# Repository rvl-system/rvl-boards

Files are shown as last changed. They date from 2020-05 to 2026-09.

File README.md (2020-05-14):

# RVL Controller Board

_**Note:**_ This board is still in development, and documentation is currently sparse.

The RVL controller board is a custom board that runs the [RVL Firmware](https://github.com/rvl-system/rvl-firmware), and is intended for use as both a development board and an LED controller. This board features:

- ESP32 dual core processor
- Compatible with 3 or 4 pin 5V LED strips supported by [FastLED](http://fastled.io/)
  - Solder jumper for switching between 3 and 4 pin headers (optional)
- Can be powered from USB, or can be "backfed" power from the LED strip connected to it
- 3.3V to 5V level translation on LED control pins
- An LCD and tiny 5-way joystick for controlling the device directly
- A 16-pin header, with GPIO, UART, JTAG, I2C, and ADC pins exposed
- Can be programmed using JTAG + [OpenOCD](https://docs.espressif.com/projects/esp-idf/en/latest/api-guides/jtag-debugging/#jtag-debugging-setup-openocd) or UART + [esptool.py](https://github.com/espressif/esptool)
  - JTAG is the recommended way to interact with this device. The experience is a lot smoother, and you can also debug the device with breakpoints/variable inspection.
  - [RVL Firmware](https://github.com/rvl-system/rvl-firmware) includes a script that is preconfigured to use JTAG+OpenOCD with this device and the [FTDI C232HM-DDHSL-0](https://www.ftdichip.com/Products/Cables/USBMPSSE.htm) MSSPE cable 
  
## GPIO Header Pins

The GPIO header has the following layout:

<table>
  <tr>
    <td>TMS</td><td>TCK</td><td>GND</td><td>26</td><td>25</td><td>18</td><td>23</td><td>VCC</td>
  </tr>
  <tr>
    <td>TDI</td><td>TDO</td><td>RXD</td><td>TXD</td><td>27</td><td>5</td><td>19</td><td>GND</td>
  </tr>
</table>

Each pin has the following functionality*:

|Pin|Functions|
|--|--|
| TMS | GPIO14, ADC2_CH6, TOUCH6, RTC_GPIO16, MTMS, HSPICLK, HS2_CLK, SD_CLK, EMAC_TXD2 |
| TDI | GPIO12, ADC2_CH5, TOUCH5, RTC_GPIO15, MTDI, HSPIQ, HS2_DATA2, SD_DATA2, EMAC_TXD3 |
| TCK | GPIO13, ADC2_CH4, TOUCH4, RTC_GPIO14, MTCK, HSPID, HS2_DATA3, SD_DATA3, EMAC_RX_ER |
| TDO | GPIO15, ADC2_CH3, TOUCH3, MTDO, HSPICS0, RTC_GPIO13, HS2_CMD, SD_CMD, EMAC_RXD3 |
| GND | Ground (shown as EN in the photo, but has been changed in the most recent revision) |
| RXD | GPIO3, U0RXD, CLK_OUT2 |
| 26  | GPIO26, DAC_2, ADC2_CH9, RTC_GPIO7, EMAC_RXD1 |
| TXD | GPIO1, U0TXD, CLK_OUT3, EMAC_RXD2 |
| 25  | GPIO25, DAC_1, ADC2_CH8, RTC_GPIO6, EMAC_RXD0 |
| 27  | GPIO27, ADC2_CH7, TOUCH7, RTC_GPIO17, EMAC_RX_DV |
| 23  | GPIO23, GPIO23, HS1_STROBE, VSPID/VSPIMOSI |
| 18  | GPIO18, GPIO18, HS1_DATA7, VSPICLK |
| 19  | GPIO19, GPIO19, U0CTS, VSPIQ/VSPMISO, EMAC_TXD0 |
| 5  | GPIO5, GPIO5, HS1_DATA6, VSPICS0, EMAC_RX_CLK |
| VCC | 3.3 volt power (limited to 500mA total including CPU) |
| GND | Ground  |

*This data comes from the [ESP32 WROOM datasheet](https://www.espressif.com/sites/default/files/documentation/esp32-wroom-32_datasheet_en.pdf).

## Photos

Here is the front of the board:

Board front

Here is the back of the board:

Board back

Here is the board running with a WS2812b LED strip attached

Board running with LEDs attached

And here is a video of an art piece I designed the lighting for using an older version of this board at Burning Man 2019:

<a href="https://www.youtube.com/watch?v=HZNM6n1g5n8" target="_blank">
  Video of the BRPL Deep Playa Branch at Burning Man 2019
</a>

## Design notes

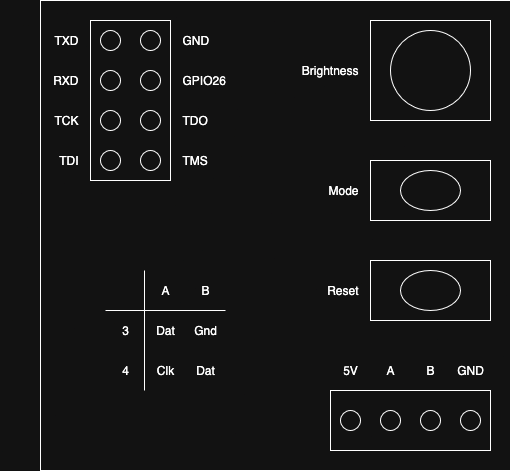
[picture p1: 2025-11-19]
receiver/pinout.png

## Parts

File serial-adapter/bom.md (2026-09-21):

# Bill of Materials

| Part Number | Description | Quantity | Unit Cost&ast; | Total Cost&ast; |
|---|---|---|---|---|
| [RMCF0805ZT0R00](https://www.digikey.com/en/products/detail/stackpole-electronics-inc/RMCF0805ZT0R00/1756901) | RES 0 OHM JUMPER 1/8W 0805 | 2 | $0.10 | $0.20 |
| [ERJ-6GEYJ222V](https://www.digikey.com/en/products/detail/panasonic-industry/ERJ-6GEYJ222V/83030) | RES SMD 2.2K OHM 5% 1/8W 0805 | 2 | $0.10 | $0.20 |
| [150080RS75000](https://www.digikey.com/product-detail/en/w-rth-elektronik/150080RS75000/732-4984-1-ND/4489916) | LED RED CLEAR 0805 SMD | 2 | $0.19 | $0.38 |
| [0532610571](https://www.digikey.com/en/products/detail/molex/0532610571/699097) | CONN HEADER SMD R/A 5POS 1.25MM | 1 | $0.85 | $0.85 |
| | CONN HDR 6POS 0.1" PITCH R/A&ast;&ast; | 1 | &mdash; | &mdash; |
| [KMR641NG ULC LFS](https://www.digikey.com/product-detail/en/c-k/KMR641NG-ULC-LFS/CKN10686CT-ND/6035358) | SWITCH TACTILE SPST-NO 50MA 32V | 2 | $0.96 | $1.92 |
| [RVL Serial Adapter board](https://oshpark.com/projects/qkIF3fA0) | Custom OSH Park board | 1 | $1.03 | $1.03 |
| | | | | **$4.58** |

&ast; All prices in USD. Prices current as of September 21st, 2026.

&ast;&ast; A generic 6 position 0.1" (2.54mm) pitch right angle pin header. These are
commonly bought as long breakaway strips and cut to size, so no specific part
number or price is listed, and it is excluded from the total.

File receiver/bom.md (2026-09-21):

# Bill of Materials

| Part Number | Description | Quantity | Unit Cost&ast; | Total Cost&ast; |
|---|---|---|---|---|
| [CC0805KKX5R5BB105](https://www.digikey.com/en/products/detail/yageo/CC0805KKX5R5BB105/5884149) | CAP CER 1UF 6.3V X5R 0805 | 1 | $0.26 | $0.26 |
| [CL21A475KQFNNNG](https://www.digikey.com/product-detail/en/samsung-electro-mechanics/CL21A475KQFNNNG/1276-6465-1-ND/5958093) | CAP CER 4.7UF 6.3V X5R 0805 | 1 | $0.13 | $0.13 |
| [CC0805MRX5R5BB106](https://www.digikey.com/en/products/detail/yageo/CC0805MRX5R5BB106/7164457) | CAP CER 10UF 6.3V X5R 0805 | 1 | $0.38 | $0.38 |
| [74479275222](https://www.digikey.com/product-detail/en/w-rth-elektronik/74479275222/732-9708-1-ND/5870862) | FIXED IND 2.2UH 2A 190 MOHM | 1 | $1.27 | $1.27 |
| [ERJ-6GEYJ680V](https://www.digikey.com/en/products/detail/panasonic-electronic-components/ERJ-6GEYJ680V/83006) | RES SMD 68 OHM 5% 1/8W 0805 | 1 | $0.10 | $0.10 |
| [ERJ-6GEYJ102V](https://www.digikey.com/product-detail/en/panasonic-electronic-components/ERJ-6GEYJ102V/P1-0KACT-ND/42833) | RES SMD 1K OHM 5% 1/8W 0805 | 1 | $0.10 | $0.10 |
| [TC33X-2-202E](https://www.digikey.com/en/products/detail/bourns-inc/TC33X-2-202E/612860) | TRIMMER 2K OHM 0.15W J LEAD TOP | 1 | $0.28 | $0.28 |
| [ERJ-6GEYJ103V](https://www.digikey.com/product-detail/en/panasonic-electronic-components/ERJ-6GEYJ103V/P10KACT-ND/43118) | RES SMD 10K OHM 5% 1/8W 0805 | 5 | $0.10 | $0.50 |
| [150080RS75000](https://www.digikey.com/product-detail/en/w-rth-elektronik/150080RS75000/732-4984-1-ND/4489916) | LED RED CLEAR 0805 SMD | 1 | $0.19 | $0.19 |
| [10118194-0001LF](https://www.digikey.com/product-detail/en/amphenol-icc-fci/10118194-0001LF/609-4618-1-ND/2785382) | CONN RCPT USB2.0 MICRO B SMD R/A | 1 | $0.47 | $0.47 |
| [OSTTE040104](https://www.digikey.com/en/products/detail/on-shore-technology-inc/OSTTE040104/2351818) | TERM BLK 4POS SIDE ENT 3.5MM PCB | 1 | $1.00 | $1.00 |
| [PPTC042LFBN-RC](https://www.digikey.com/en/products/detail/sullins-connector-solutions/PPTC042LFBN-RC/810211) | CONN HDR 8POS 0.1 TIN PCB | 1 | $0.65 | $0.65 |
| [219-3LPST](https://www.digikey.com/en/products/detail/cts-electrocomponents/219-3LPST/223166) | SWITCH DIP SLIDE SPST 100MA 20V | 1 | $0.54 | $0.54 |
| [KMR641NG ULC LFS](https://www.digikey.com/product-detail/en/c-k/KMR641NG-ULC-LFS/CKN10686CT-ND/6035358) | SWITCH TACTILE SPST-NO 50MA 32V | 2 | $0.96 | $1.92 |
| [ESP32-WROOM-32E](https://www.digikey.com/en/products/detail/espressif-systems/ESP32-WROOM-32E-N4/11613125) | ESP-32 WiFi Microcontroller | 1 | $4.99 | $4.99 |
| [LM3671MF-3.3/NOPB](https://www.digikey.com/product-detail/en/texas-instruments/LM3671MF-3.3-NOPB/LM3671MF-3.3-NOPBCT-ND/1590190) | IC REG BUCK 3.3V 600MA SOT23-5 | 1 | $1.99 | $1.99 |
| [SN74LVC1T45DBVR](https://www.digikey.com/product-detail/en/texas-instruments/SN74LVC1T45DBVR/296-16843-1-ND/639459) | IC TRNSLTR BIDIRECTIONAL SOT23-6 | 2 | $0.62 | $1.24 |
| [RVL Receiver v1.7 board](https://oshpark.com/shared_projects/RHi5VRXz) | Custom OSH Park board | 1 | $3.76 | $3.76 |
| | | | | **$19.77** |

&ast; All prices in USD. Prices current as of September 21st, 2026.

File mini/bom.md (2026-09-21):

# Bill of Materials

| Part Number | Description | Quantity | Unit Cost&ast; | Total Cost&ast; |
|---|---|---|---|---|
| [CL21B104KCCWPNC](https://www.digikey.com/en/products/detail/samsung-electro-mechanics/CL21B104KCCWPNC/5961334) | CAP CER 0.1UF 100V X7R 0805 | 2 | $0.29 | $0.58 |
| [CC0805KKX5R5BB105](https://www.digikey.com/en/products/detail/yageo/CC0805KKX5R5BB105/5884149) | CAP CER 1UF 6.3V X5R 0805 | 1 | $0.26 | $0.26 |
| [CL21A475KQFNNNG](https://www.digikey.com/product-detail/en/samsung-electro-mechanics/CL21A475KQFNNNG/1276-6465-1-ND/5958093) | CAP CER 4.7UF 6.3V X5R 0805 | 1 | $0.13 | $0.13 |
| [CC0805MRX5R5BB106](https://www.digikey.com/en/products/detail/yageo/CC0805MRX5R5BB106/7164457) | CAP CER 10UF 6.3V X5R 0805 | 1 | $0.38 | $0.38 |
| [74479275222](https://www.digikey.com/product-detail/en/w-rth-elektronik/74479275222/732-9708-1-ND/5870862) | FIXED IND 2.2UH 2A 190 MOHM | 1 | $1.27 | $1.27 |
| [ERJ-6GEYJ680V](https://www.digikey.com/en/products/detail/panasonic-industry/ERJ-6GEYJ680V/83006) | RES SMD 68 OHM 5% 1/8W 0805 | 1 | $0.10 | $0.10 |
| [ERJ-6GEYJ221V](https://www.digikey.com/en/products/detail/panasonic-electronic-components/ERJ-6GEYJ221V/89706) | RES SMD 220 OHM 5% 1/8W 0805 | 1 | $0.10 | $0.10 |
| [ERJ-6GEYJ331V](https://www.digikey.com/en/products/detail/panasonic-industry/ERJ-6GEYJ331V/89726) | RES SMD 330 OHM 5% 1/8W 0805 | 2 | $0.10 | $0.20 |
| [ERJ-6GEYJ103V](https://www.digikey.com/product-detail/en/panasonic-electronic-components/ERJ-6GEYJ103V/P10KACT-ND/43118) | RES SMD 10K OHM 5% 1/8W 0805 | 1 | $0.10 | $0.10 |
| [ERJ-6GEYJ123V](https://www.digikey.com/en/products/detail/panasonic-industry/ERJ-6GEYJ123V/83066) | RES SMD 12K OHM 5% 1/8W 0805 | 1 | $0.10 | $0.10 |
| [LTRB RASF.01-6B6C-C3E6-0-0-R18](https://www.digikey.com/en/products/detail/ams-osram-ag/LTRB-RASF-01-6B6C-C3E6-0-0-R18/26240997) | LED RGBW DIFFUSED SMD 1010 | 1 | $0.68 | $0.68 |
| [10118194-0001LF](https://www.digikey.com/product-detail/en/amphenol-icc-fci/10118194-0001LF/609-4618-1-ND/2785382) | CONN RCPT USB2.0 MICRO B SMD R/A | 1 | $0.47 | $0.47 |
| [OSTTE030104](https://www.digikey.com/en/products/detail/on-shore-technology-inc/OSTTE030104/2351817) | TERM BLK 3POS SIDE ENT 3.5MM PCB | 1 | $0.77 | $0.77 |
| [0532610571](https://www.digikey.com/en/products/detail/molex/0532610571/699097) | CONN HEADER SMD R/A 5POS 1.25MM | 1 | $0.85 | $0.85 |
| [ESP32-WROOM-32E](https://www.digikey.com/en/products/detail/espressif-systems/ESP32-WROOM-32E-N4/11613125) | ESP-32 WiFi Microcontroller | 1 | $4.99 | $4.99 |
| [LM3671MF-3.3/NOPB](https://www.digikey.com/product-detail/en/texas-instruments/LM3671MF-3.3-NOPB/LM3671MF-3.3-NOPBCT-ND/1590190) | IC REG BUCK 3.3V 600MA SOT23-5 | 1 | $1.99 | $1.99 |
| [SN74LVC1T45DBVR](https://www.digikey.com/product-detail/en/texas-instruments/SN74LVC1T45DBVR/296-16843-1-ND/639459) | IC TRNSLTR BIDIRECTIONAL SOT23-6 | 1 | $0.62 | $0.62 |
| [RVL Mini v1.0 board](https://oshpark.com/shared_projects/aRHhIKgn) | Custom OSH Park board | 1 | $3.03 | $3.03 |
| | | | | **$16.62** |

&ast; All prices in USD. Prices current as of September 21st, 2026.

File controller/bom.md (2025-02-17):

# Bill of Materials

| Part Number | Description | Quantity | Unit Cost&ast; | Total Cost&ast; |
|---|---|---|---|---|
| [10118194-0001LF](https://www.digikey.com/product-detail/en/amphenol-icc-fci/10118194-0001LF/609-4618-1-ND/2785382) | CONN RCPT USB2.0 MICRO B SMD R/A | 1 | $0.46 | $0.46 |
| [ CL21A475KQFNNNG](https://www.digikey.com/product-detail/en/samsung-electro-mechanics/CL21A475KQFNNNG/1276-6465-1-ND/5958093) | CAP CER 4.7UF 6.3V X5R 0805 | 1 | $0.10 | $0.10 |
| [ CC0805MRX5R5BB106](https://www.digikey.com/en/products/detail/yageo/CC0805MRX5R5BB106/7164457) | CAP CER 10UF 6.3V X5R 0805 | 1 | $0.14 | $0.14 |
| [ CC0805KKX5R5BB105](https://www.digikey.com/en/products/detail/yageo/CC0805KKX5R5BB105/5884149) | CAP CER 1UF 6.3V X5R 0805 | 1 | $0.17 | $0.17 |
| [ 74479275222](https://www.digikey.com/product-detail/en/w-rth-elektronik/74479275222/732-9708-1-ND/5870862) | FIXED IND 2.2UH 1.3A 176 MOHM  | 1 | $1.27 | $1.27 |
| [150080RS75000](https://www.digikey.com/product-detail/en/w-rth-elektronik/150080RS75000/732-4984-1-ND/4489916) | LED RED CLEAR 0805 SMD | 1 | $0.19 | $0.19 |
| [ERJ-6GEYJ102V](https://www.digikey.com/product-detail/en/panasonic-electronic-components/ERJ-6GEYJ102V/P1-0KACT-ND/42833) | RES SMD 1K OHM 5% 1/8W 0805 | 1 | $0.10 | $0.10 |
| [ERJ-6GEYJ221V](https://www.digikey.com/en/products/detail/panasonic-electronic-components/ERJ-6GEYJ221V/89706) | RES SMD 220 OHM 5% 1/8W 0805 | 2 | $0.10 | $0.20 |
| [LM3671MF-3.3/NOPB](https://www.digikey.com/product-detail/en/texas-instruments/LM3671MF-3.3-NOPB/LM3671MF-3.3-NOPBCT-ND/1590190) | IC REG BUCK 3.3V 600MA SOT23-5 | 1 | $1.66 | $1.66 |
| [ERJ-6GEYJ103V](https://www.digikey.com/product-detail/en/panasonic-electronic-components/ERJ-6GEYJ103V/P10KACT-ND/43118) |  	RES SMD 10K OHM 5% 1/8W 0805 | 3 | $0.10 | $0.30 |
| [KMR641NG ULC LFS](https://www.digikey.com/product-detail/en/c-k/KMR641NG-ULC-LFS/CKN10686CT-ND/6035358) | SWITCH TACTILE SPST-NO 50MA 32V | 2 | $0.80 | $1.60 |
| [ESP32-WROOM-32E](https://www.digikey.com/en/products/detail/espressif-systems/ESP32-WROOM-32E-N4/11613125) | ESP-32 WiFi Microcontroller | 1 | $2.50 | $2.50 |
| [744C083103JP](https://www.digikey.com/product-detail/en/cts-resistor-products/744C083103JP/744C083103JPCT-ND/1117754) (Needs replacement) | RES ARRAY 4 RES 10K OHM 2012 | 1 | $0.45 | $0.45 |
| [SF3O3GJ2](https://www.sparkfun.com/products/10063) | 5-way Tactile Switch | 1 | $2.10 | $2.10 |
| [SSD1306](https://www.amazon.com/gp/product/B01HHOAQ5A/) | 128x64 pixel OLED I2C display | 1 | $11.59 | $11.59 |
| [SN74LVC1T45DBVR](https://www.digikey.com/product-detail/en/texas-instruments/SN74LVC1T45DBVR/296-16843-1-ND/639459) | IC TRNSLTR BIDIRECTIONAL SOT23-6 | 2 | $0.55 | $1.10
| [RVL Controller v1.7 board](https://oshpark.com/shared_projects/RHi5VRXz) | Custom OSH Park board | 1 | $7.93 | $7.93 |
| | | | | **$31.69** |

### Optional add-ons

| Part Number | Description | Quantity | Unit Cost&ast; | Total Cost&ast; |
|---|---|---|---|---|
| [PRT-15519](https://www.sparkfun.com/products/15519) | 4 position Screw Terminals | 1 | $1.05 | $1.05 |
| [PRT-13156](https://www.sparkfun.com/products/13156) | Header - 2x8 (Male, 0.1") | 1 | $0.24 | $0.24 |
| [PPTC031LGBN-RC](https://www.digikey.com/product-detail/en/sullins-connector-solutions/PPTC031LGBN-RC/S5439-ND/775897) | CONN HDR 3POS 0.1 TIN PCB R/A | 1 | $0.50 | $0.50 |
| [PPTC041LGBN-RC](https://www.digikey.com/products/en?keywords=%20PPTC041LGBN-RC%20) | CONN HDR 4POS 0.1 TIN PCB R/A | 1 | $0.56 | $0.56 |

&ast; All prices in USD. Prices current as of June 2nd, 2024.

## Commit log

2019-10-01 Lots of progress
    [hub.sch]
2019-10-01 First draft of serial interface
    [hub.sch]
2019-10-01 Added joystick
    [hub.sch]
2019-10-02 Finished headers
    [hub.brd, hub.sch]
2019-10-02 First draft complete?
    [hub.brd, hub.sch]
2019-10-07 Tweaked and confirmed some connections
    [hub.brd, hub.sch]
2019-10-08 More component arrangement
    [hub.brd, hub.sch]
2019-10-09 First draft of device placement
    [hub.brd, hub.sch]
2019-10-10 First draft of component layout
    [hub.brd, hub.sch]
2019-10-25 Finished placing components and started laying out traces
    [hub.brd, hub.sch]
2019-10-27 Wired up lots of support circuitry
    [hub.brd, hub.sch]
2019-10-27 Finished layout!
    [hub.brd, hub.sch]
2019-10-27 Final tweaks and BOM creation
    [hub.brd, hub.sch]
2019-11-19 Fixed a bunch of bugs in v1.0
    [controller.brd, controller.sch]
2019-12-23 Tweaks and bug fixes from v1.1 board
    [controller.brd, controller.sch]
2020-02-01 Made a lot of progress with redesign
    [controller.brd, controller.sch]
2020-02-01 Finished placing parts
    [controller.brd]
2020-02-02 Finished v1.2
    [controller.brd, controller.sch]
2020-03-12 Version 1.3
    [controller.brd, controller.sch]
2020-04-20 Fixed pin labelling
    [controller.brd, controller.sch]
2020-06-20 Switched to using a submodule for external components
    [controller.brd]
2020-07-13 Updated BOM
2020-07-15 Finished v1.5
    [controller.brd]
2024-06-03 Converted project back to KiCad
    [ESP.kicad_sch, Extension_Headers.kicad_sch, LED.kicad_sch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]
2024-07-14 Bug fix
    [ESP.kicad_sch, controller.kicad_pcb]
2024-07-20 More tuned LED resistor
    [LED.kicad_sch]
2025-02-17 Moved controller board into sub folder
    [ESP.kicad_sch, Extension_Headers.kicad_sch, LED.kicad_sch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]
2025-02-17 Cleaned up controller
    [ESP.kicad_sch, Extension_Headers.kicad_sch, LED.kicad_sch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]
2025-02-18 First draft of receiver board
    [ESP.kicad_sch, Extension_Headers.kicad_sch, LED.kicad_sch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]
2025-11-19 Saving previous version of receiver
    [ESP.kicad_sch, Extension_Headers.kicad_sch, LED.kicad_sch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]
2025-12-05 First draft of new board
    [ESP.kicad_sch, Extension_Headers.kicad_sch, Power.kicad_sch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]
2025-12-05 First draft of new receiver
    [ESP.kicad_sch, Extension_Headers.kicad_sch, LED.kicad_sch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]
2025-12-07 Finished first draft of new receiver
    [ESP.kicad_sch, Extension_Headers.kicad_sch, UI.kicad_sch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]
2026-09-19 Created new mini project scaffolding
    [esp.kicad_sch, leds.kicad_sch, mini.kicad_pcb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]
2026-09-19 Created proper local symbol library
    [mini.kicad_sch]
2026-09-19 Added usb plug part
    [mini.kicad_sch]
2026-09-19 Created power page schematic
    [mini.kicad_pcb, mini.kicad_sch]
2026-09-19 Added LED output
    [leds.kicad_sch, mini.kicad_pcb, serial.kicad_sch]
2026-09-19 First draft of non-uart schematics
    [esp.kicad_sch, mini.kicad_pcb, mini.kicad_sch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]
2026-09-20 First draft of mini board
    [esp.kicad_sch, leds.kicad_sch, mini.kicad_pcb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]
2026-09-20 Schematic polish
    [esp.kicad_sch, leds.kicad_sch]
2026-09-20 Finished regulator layout
    [esp.kicad_sch, mini.kicad_pcb]
2026-09-20 Finished layout of the level translator
    [mini.kicad_pcb]
2026-09-20 First draft of finished mini board
    [esp.kicad_sch, leds.kicad_sch, mini.kicad_pcb]
2026-09-20 Got DRC to pass
    [mini.kicad_pcb]
2026-09-21 Finishing touches
    [esp.kicad_sch, mini.kicad_pcb]
2026-09-21 Finished serial adapter
    [serial-adapter.kicad_pcb, serial-adapter.kicad_sch]
2026-09-21 Added missing labels to mini
    [mini.kicad_pcb]
2026-09-21 Added mini BOM
2026-09-21 restored v1.7 of receiver, since 2.0 is abandoned
    [ESP.kicad_sch, Extension_Headers.kicad_sch, LED.kicad_sch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]
2026-09-21 Updated receiver BOM
2026-09-21 Added serial adapter BOM
